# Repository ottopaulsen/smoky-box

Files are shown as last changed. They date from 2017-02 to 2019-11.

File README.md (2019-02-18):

# Smoky Box

Se beskrivelse i [smoky](https://github.com/ottopaulsen/smoky)

## NodeMCU

NodeMCU Pinout

## Vifte

Cooler Master A9225-...
12V, 0.6A

Pinout:
Sort: GND
Rød: 12V
Gul: Sense. Open collector. Kan kobles til 3,3V eller 5V. Frekvens forteller hastighet.
Blå: Control. PWM kontrollerer farta. 3,3V fungerer.

Use analogWrite() to write a value between 0 and 1023 on any of pin 0-8. You may not use the serial port if you use the serial pins.

## Components

DHT22 pinout:

DHT22 Pinout

The DHT22 is connected using a 3 pin 3,5mm jack as follows:

* GND is connected to the outer part
* VCC is connected to the middle part
* Data is connected to the inner part (center)

## Generell doc

[ESP8266 Reference Doc](http://arduino.esp8266.com/versions/1.6.5-1160-gef26c5f/doc/reference.html) Lots of useful information.

[How to connect and program the ESP8266](doc/ESP8266 Programming.md)

[Programming the NodeMCU](doc/NodeMCU.md)

[220V Detector](doc/220V detector.md)

[OTA Update](http://esp8266.github.io/Arduino/versions/2.0.0/doc/ota_updates/ota_updates.html) "Over the air" update av firmware i ESP8266. Jeg bruker [Web Browser varianten](http://esp8266.github.io/Arduino/versions/2.0.0/doc/ota_updates/ota_updates.html#web-browser)

[Integrating with Homekit](doc/Homekit.md)

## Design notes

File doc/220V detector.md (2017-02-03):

# 220C Detektor for varmeelement

Jeg ønsker å bruke røykskapet også for tørking av kjøtt. Hvis det skal skje om vinteren ønsker jeg å unngå at det fryser. Derfor har jeg installert et varmeelement på 100W, som styres av en termostat. For å finne ut hvor mye strøm som går med til denne oppvarmingen ønsker jeg å detektere når varmeelementet er på og når det er av, og så beregne strømforbruket ut fra dette.

Jeg må derfor koble 220V-signalet til varmeelementet inn på arduinoen. Dette gjør jeg via en [HLK-PM03](http://www.ebay.com/itm/272252759542?_trksid=p2057872.m2749.l2649&ssPageName=STRK%3AMEBIDX%3AIT) 220V AC til 5V DC omformer. Jeg skal vurdere å også bruke en optocoupler for å være sikker på at forstyrrelser på 220V-nettet ikke ødelegger arduinoen.

Min optocoupler er en EL817 ([datasheet](http://www.everlight.com/file/ProductFile/EL817.pdf)). Spenning inn skal være 1.2V, og den trekker 60 mA. Motstanden mellom anode og 5V skal da være:

R = U / I = (5V-1.2V) / 0.06A = 63 ohm.

Hvis jeg derimot bruker en 3.3V kilde skal motstanden være:

R = U / I = (3.3V-1.2V) / 0.06A = 35 ohm.

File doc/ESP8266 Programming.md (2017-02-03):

# ESP8266 Programming

The ESP8266 is a very affordable board with built in wifi, that can be programmed like an Arduino. It is small in size, but the simplest version only have two GPIO-ports. There are however other versions with more connections.

## Connecting the ESP8266 for flashing

In order to program it you need to connect it to your computer via an FTDI adapter. It may get power from your USB port via the FTDI adapter, provided you have an FTDI adapter with 3.3V output, but that is risky, since the wifi module uses a lot of power. I crashed my mac doing that, so I connected it to a separate power supply in stead.

Here is how you connect it all together for programming (flashing) the ESP8266 with your own software, for example using the Arduino IDE:

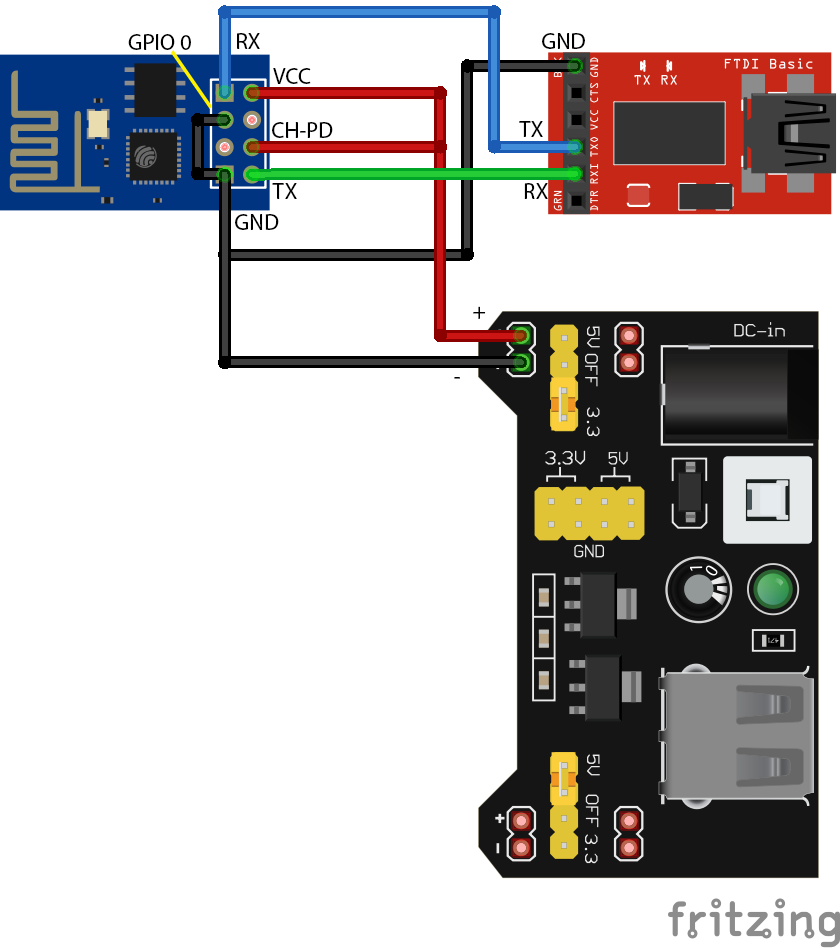
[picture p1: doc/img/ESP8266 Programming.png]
ESP8266 connection for programming


The power supply used here is a breadboard power supply that is connected to a 12V power supply and outputs 3.3V and 5V. You can use anything that gives you 3.3V with a few hundred milliamps.

Make sure you use the 3.3V power to the ESP8266!

There are many different ESP8266 boards, and many different FTDI adapters, so make sure you connect them right.

Also make sure you use 3.3V I/O level on the FTDI board. The FT232RL has a jumper where you can switch between 3.3V and 5V, and is convenient. If you only have 5V FTDI, buy a new, or create a voltage divider using two resistors on the TX port, so the RX port on the ESP8266 gets 3.3V.

### Wire connections

ESP8266          | FTDI             | Power            
---------------- | ---------------- | -----------------
GND              | GND              | GND (-)          
VCC              | <Do NOT connect> | + 3.3V           
RX               | TX               |                  
TX               | RX               |                  
CH-PD to VCC     |                  |                  
GPIO 0 to GND    |                  |                  
                 | USB to computer  | Power input for example from a std. 12V power supply

* Connect GND (-) on all boards together.
* The FTDI board gets VCC (+) from the USB port. VCC on the FTDI board should NOT be connected.
* Connect RX to TX and vice versa. 
* CH-PD is connected to VCC for some reason I don't remember.
* GPIO 0 is connected to GND to boot the ESP8266 in flash mode. Remember, this connection is for flashing.

-----

Here is pinout for this version of the ESP8266:

ESP8266 Pinout

Since you are probably going to connect the ESP8266 this way many times, it is a good idea to create a special cable for this purpose. Here is mine:

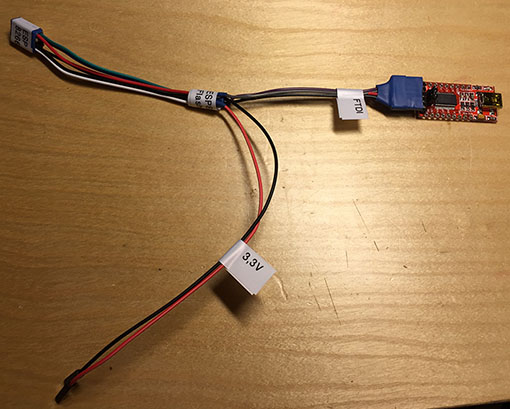
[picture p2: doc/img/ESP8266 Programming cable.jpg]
ESP8266 Programming cable


I used standard dupont wire cables for all the pins, and just cut away the wires on unused connectors. Then I used shrink plastic to hold them together, but tape would probably also do. The cables that should be connected to multiple ends, I soldered in the middle, and isolated with shrink plastic (tape would do).

## Flashing the ESP8266

You can use the Arduino IDE, and write code as for any other Arduino, to program the ESP8266. Just remember that it has very limited IO-ports.

Connect the board to the computer using an FTDI adapter, an external power supply and a cable as described above.

Please note that you need to install a driver for the FDTI adapter, if you haven't done that before.

In the Arduino IDE, select the right port for the FTDI adapter. On my mac it is /dev/cu.usbserial-A50285BI, but it may be different. It is easy to find, because it is visible in the Arduino IDE menu when the FTDI adapter is connected (and the driver is installed), and not visible when not connected.

Some times I have to restart my mac in order to find the USB port in the Arduino IDE. I haven't tried to find out why.

As board, select "Generic ESP8266 Module". If it is not there, it can be installed using the Board manager. Search for ESP8266.

### Example

As an example for using the ESP8266, I have connected it to a DHT22 which can read temperature and humidity, and I transfer the data to [ThingsPeak.com](https://thingspeak.com/) via wifi so I can read them on the internet.

Here is the wiring:

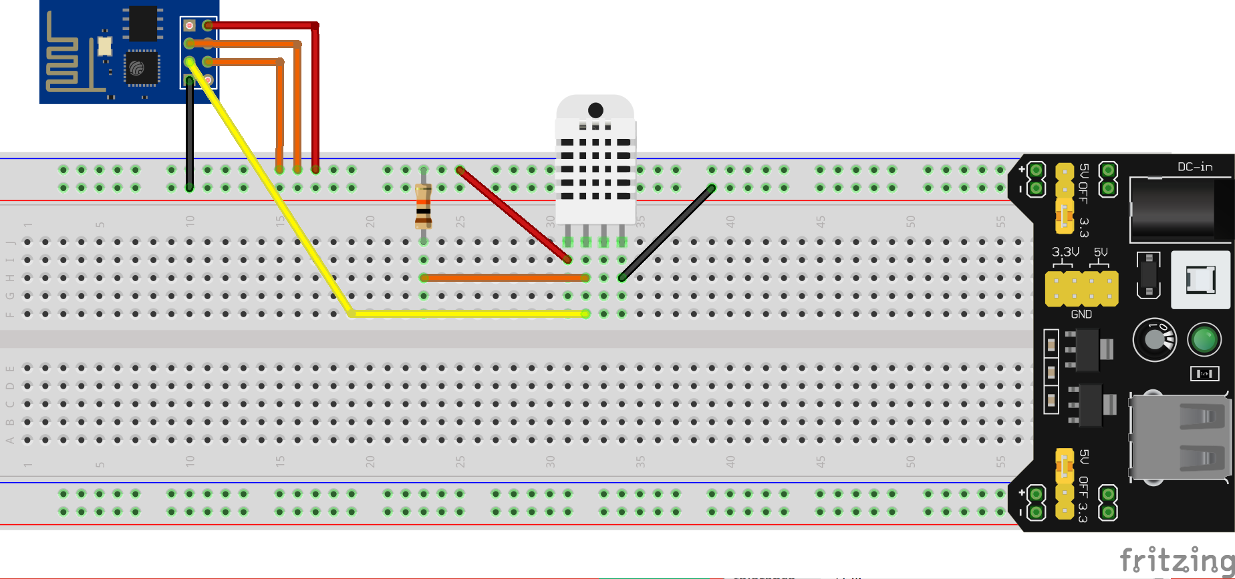
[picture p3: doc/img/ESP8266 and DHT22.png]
ESP8266 and DHT22 wiring


Double check that you are using 3.3V from the power supply!

In order to use ThingSpeak.com, just create an account and a channel. It is very easy. You need to find the channel id and the API key in there, but that should not be too hard.

Below is the example code. It reads humidity and temperature from the sensor, and transfer it to ThingSpeak.com every minute.

```cpp
#include "DHT.h"
#include "ThingSpeak.h"
#include "ESP8266WiFi.h"

#define DHTPIN 2
#define DHTTYPE DHT22

DHT dht(DHTPIN, DHTTYPE);
WiFiClient  client;

char ssid[] = "YourNetwork";
char pass[] = "yournetworkpassword";
unsigned long myChannelNumber = 12345;
const char * myWriteAPIKey = "SECRETTHINGSPEAKKEY";

long previousMillis = 0;
long interval = 60000;

void setup() {
  WiFi.begin(ssid, pass);
  ThingSpeak.begin(client);
  dht.begin();
}

void loop() {
  unsigned long currentMillis = millis();
  if(currentMillis - previousMillis > interval) {
    previousMillis = currentMillis;
    float temperature = dht.readTemperature();
    float humidity = dht.readHumidity();
    ThingSpeak.setField(1, temperature);
    ThingSpeak.setField(2, humidity);
    ThingSpeak.writeFields(myChannelNumber, myWriteAPIKey);
  }
}
```
Create a new Arduino project, paste the code, enter the right data for

* Wifi network SSID
* Wifi password
* ThingSpeak channel
* ThingSpeak API key

Compile and upload the code to the ESP8266 using the flash connection above. Remove the flash-connector and connect the parts as described above with the DHT22. Power up, wait a minute and take a look at ThingSpeak.com.

In order to just test ThingSpeak.com, here is a very simple Python script that transfers som fake data:

```python
import requests
import random
from time import sleep

url = 'https://api.thingspeak.com/update'
key = 'SECRETTHINGSPEAKKEY2'
channel = 12346

temp = random.uniform(10,25)
hum = random.uniform(10, 80)

for t in range(120):
    temp += random.random() - 0.5
    hum += (random.random() - 0.5) * 3
    data = {'channel_id': channel, 'api_key': key, 'field1': temp, 'field2': hum}
    res = requests.post(url, data=data)
    if res.status_code == 200:
        print('Successfully updated channel with:  Temp: {}   Hum: {}'.format(temp, hum))
    sleep(60)

```

Thingspeak logo white
Channels 
Apps
Blog
Support 
Account 
Sign Out
Smoky
Channel ID: 144820
Author: ottopaulsen
Access: Public Data from smoke house
Private View
Public View
Channel Settings
API Keys
Data Import / Export

 Add Visualizations  Data Export
MATLAB Analysis MATLAB Visualization
Channel Stats
Created 12 days ago
Updated less than a minute ago
Last Entry  less than a minute ago
5434 Entries
Field 1 Chart

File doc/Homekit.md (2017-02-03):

# Integrating with Homekit

## Introduction

I want to control the smoky box from my iPhone, and why not use [Homekit](https://developer.apple.com/library/content/documentation/NetworkingInternet/Conceptual/HomeKitDeveloperGuide/Introduction/Introduction.html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)? There is a tool called [Homebridge](https://github.com/nfarina/homebridge) that can be used to integrate with Homekit.

I have a Raspberry Pi 3 with [Ubuntu Mate](https://ubuntu-mate.org/) installed. It is doing almost nothing, so I want to install homebridge there, for this purpose.

## Installation log

Ubuntu Mate is already running on my Pi, so I start following the [installation instructions](https://github.com/nfarina/homebridge#installation) for Homebridge, including some of the things mentioned in the Raspberry Pi [Wiki](https://github.com/nfarina/homebridge/wiki/Running-HomeBridge-on-a-Raspberry-Pi).

One note about [Installing Homebridge and dependencies](https://github.com/nfarina/homebridge/wiki/Running-HomeBridge-on-a-Raspberry-Pi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): On Ubuntu Mate, the node_modules are installed under `/usr/lib`, not `/usr/local/lib`.

Installed the [homebridge-mqtt-temperature plugin](https://www.npmjs.com/package/homebridge-mqtt-temperature), the [homebridge-mqtt-humidity plugin](https://www.npmjs.com/package/homebridge-mqtt-humidity) and the [mqtt library](https://www.npmjs.com/package/mqtt).

According to the installation instructions for homebridge, it should not work until I created the config.json file. However, it did start without this file. Probably because there were some files under the accessories and the persist directories in the ~/.homebridge folder. I deleted those directories and created a new config.json file like this:
```
{
  "bridge": {
    "name": "HomeBridge-Otto",
    "username": "AC:33:3B:D3:CE:32",
    "port": 55149,
    "pin": "031-45-154"
  },

  "description": "Otto sin homebridge hjemme",

  "accessories": [
    {
      "accessory": "mqtt-temperature",
      "name": "Smoky temperatur",
      "url": "mqtt://m20.cloudmqtt.com:15555",
      "topic": "smoky/1/inside/temperature",
      "username": "henqvddw",
      "password": "hemmelig"
    },
    {
      "accessory": "mqtt-humidity",
      "name": "Smoky luftfuktighet",
      "url": "mqtt://m20.cloudmqtt.com:15555",
      "topic": "smoky/1/inside/humidity",
      "username": "henqvddw",
      "password": "hemmelig"
    }
  ],

  "platforms": []
}
```

The name can be anything.
I have tried to figure out what the username is, without luck, but you can change it to something with legal hex numbers, I think. I believe you can select the port you like (as long as it is not used by something else), and also the pin, but the format must be the same.

The accessory is the name of the plugins, and if you have an MQTT running, you will recognize the other values under accessories.

I found the homebridge in the Home app on my iPhone, but every time I restarted homebridge, I had to set ig up again. I dont know why. Should not be necessary.

## References

[Introduction to Homekit (apple)](https://developer.apple.com/library/content/documentation/NetworkingInternet/Conceptual/HomeKitDeveloperGuide/Introduction/Introduction.html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)

[Homebridge (Node)](https://github.com/nfarina/homebridge)

[Homebridge on RaspberryPi](https://github.com/nfarina/homebridge/wiki/Running-HomeBridge-on-a-Raspberry-Pi)

[Homecontrol (go)](http://selfcoded.com/homecontrol/)

[Plugin simple example](https://github.com/nfarina/homebridge/tree/6500912f54a70ff479e63e2b72760ab589fa558a/example-plugins/homebridge-lockitron)

[Homebridge MQTT switch](https://www.npmjs.com/package/homebridge-mqttswitch)

[Homebridge MQTT temperature](https://www.npmjs.com/package/homebridge-mqtt-temperature)

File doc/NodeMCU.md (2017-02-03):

# Programming the NodeMCU

In order to program the NodeMCU you need the [CH340 driver](http://www.wemos.cc/downloads/). That will (on mac) give you the /dev/cu.wchusbserial1420 port available in the Arduino IDE.

Then follow [these instructions](http://www.instructables.com/id/Quick-Start-to-Nodemcu-ESP8266-on-Arduino-IDE/) to try it using a blinking led.

Here is [pinout](https://github.com/nodemcu/nodemcu-devkit) and other info about the NodeMCU.

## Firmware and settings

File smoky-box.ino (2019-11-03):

#include <PubSubClient.h>
#include <DHTesp.h>
#include <ESP8266WiFi.h>
#include <ESP8266WebServer.h>
#include <ESP8266mDNS.h>
#include <ESP8266HTTPUpdateServer.h>
#include <PID_v1.h>
#include <EEPROM.h>

#include "secrets.h"
/*
 * Secrets are: 
 *   #define WIFIPASSWORD "secret"
 *   #define MQTTPASSWORD "secret"
 *   #define UPDATEOTAPASSWORD "secret"
 */

/* GPIO Allocation
 * 
 * D0 GPIO16
 * D1 GPIO5
 * D2 GPIO4 DHT Inside
 * D3 GPIO0
 * D4 GPIO2 DHT Outside
 * D5 GPIO14 DHT Box
 * D6 GPIO12 Heater
 * D7 GPIO13 Green LED
 * D8 GPIO15 
 * RX GPIO3 Fan vent PWM
 * TX GPIO1 Fan vent sensor
 */

#define SMOKY_ID "1"
#define PRODUCTION 1 // 1 to go Live, 0 to test

// WiFi
const char* wifiSsid = "Xtreme";
const char* wifiPassword = WIFIPASSWORD;
WiFiClient  wifiClient;

// MQTT
const char* mqttServer = "10.0.0.15";
const char* mqttUser = "ottomq";
const char* mqttPassword = MQTTPASSWORD;
const long mqttPort = 1883;
const long mqttInterval = 10000;
unsigned long mqttPreviousSentMillis = 0;
PubSubClient mqttClient(wifiClient);

// MQTT Topics
#define MQTT_TOPIC_OUT "smoky/" SMOKY_ID
#define MQTT_TOPIC_IN "smoky/" SMOKY_ID "/in"
const char* mqttTopicInsideTemperature = MQTT_TOPIC_OUT "/inside/temperature";
const char* mqttTopicInsideHumidity = MQTT_TOPIC_OUT "/inside/humidity";
const char* mqttTopicOutsideTemperature = MQTT_TOPIC_OUT "/outside/temperature";
const char* mqttTopicOutsideHumidity = MQTT_TOPIC_OUT "/outside/humidity";
const char* mqttTopicBoxTemperature = MQTT_TOPIC_OUT "/box/temperature";
const char* mqttTopicBoxHumidity = MQTT_TOPIC_OUT "/box/humidity";
const char* mqttTopicSmoke = MQTT_TOPIC_OUT "/inside/smoke";
const char* mqttTopicHeaterPercent = MQTT_TOPIC_OUT "/inside/heaterpercent";
const char* mqttTopicHeaterOutput = MQTT_TOPIC_OUT "/inside/heateroutput";
const char* mqttTopicOutSettingsTemp = MQTT_TOPIC_OUT "/settings/temp";
const char* mqttTopicOutSettingsKp = MQTT_TOPIC_OUT "/settings/kp";
const char* mqttTopicOutSettingsKi = MQTT_TOPIC_OUT "/settings/ki";
const char* mqttTopicOutSettingsKd = MQTT_TOPIC_OUT "/settings/kd";
const char* mqttTopicOutSettingsFanVent = MQTT_TOPIC_OUT "/settings/fan_vent";
const char* mqttTopicOutSettingsHeaterOutput = MQTT_TOPIC_OUT "/settings/heateroutput";
const char* mqttTopicOutConnecting = MQTT_TOPIC_OUT "/connecting";
const char* mqttTopicDhtReadFailures = MQTT_TOPIC_OUT "/dhtreadfailures";
const char* mqttTopicOutMsg = MQTT_TOPIC_OUT "/msg";
const char* mqttTopicFanVentSetting = MQTT_TOPIC_OUT "/fan_vent/setting";
const char* mqttTopicFanVentSpeed = MQTT_TOPIC_OUT "/fan_vent/speedRPM";
const char* mqttTopicLooptimeMax = MQTT_TOPIC_OUT "/looptime/max";
const char* mqttTopicLooptimeMin = MQTT_TOPIC_OUT "/looptime/min";
const char* mqttTopicLooptimeAverage = MQTT_TOPIC_OUT "/looptime/average";
const char* mqttTopicLooptimeLatest = MQTT_TOPIC_OUT "/looptime/latest";
const char* mqttTopicLooptimeCount = MQTT_TOPIC_OUT "/looptime/count";

const char* mqttTopicInAck = MQTT_TOPIC_IN "/ack";
const char* mqttTopicInSetTemp = MQTT_TOPIC_IN "/temp";
const char* mqttTopicInSetKp = MQTT_TOPIC_IN "/kp";
const char* mqttTopicInSetKi = MQTT_TOPIC_IN "/ki";
const char* mqttTopicInSetKd = MQTT_TOPIC_IN "/kd";
const char* mqttTopicInSetFanVent = MQTT_TOPIC_IN "/fan_vent";
const char* mqttTopicInReadSettings = MQTT_TOPIC_IN "/read";

// MQTT Status
#define MQTT_STATUS_UNKNOWN 0
#define MQTT_STATUS_SENDING 1
#define MQTT_STATUS_ACKNOWLEDGED 2
#define MQTT_STATUS_FAILED 3
#define GREENLED 13
const long ledInterval = 250;
unsigned int mqttStatus = MQTT_STATUS_UNKNOWN;
bool greenLed = false;
unsigned long ledPreviousMillis = 0;

// Smoke
#define SMOKEPIN A0

// Temperature and humidity
#define DHTINSIDE 4 // D2
#define DHTOUTSIDE 2 // D4
#define DHTBOX 14 // D5

#define DHTTYPE DHTesp::AM2302
DHTesp dhtInside;
DHTesp dhtOutside;
DHTesp dhtBox;
double temperatureInside =  5.0;
float humidityInside = 0.0;
float temperatureOutside = 0.0;
float humidityOutside = 0.0;
float temperatureBox = 0.0;
float humidityBox = 0.0;
unsigned long dhtReadFailures = 0;
unsigned long dhtReadInterval = 2500; 
unsigned long dhtPreviousReadMillis = 0;

// EEPROM Settings
#define SETTINGS_VERSION 101
#define DEFAULT_KP 5.0
#define DEFAULT_KI 0.05
#define DEFAULT_KD 0.5
#define DEFAULT_TEMP 5.0
#define DEFAULT_FAN 10
struct SmokySettings {
  int version; // Figure ot if data has been saved before
  float Kp;
  float Ki;
  float Kd;
  double temp;
  int fanVent;
};
SmokySettings settings;


// Heater control
#define HEATERPIN 12 // D6
#define HEATER_PID_SAMPLE_TIME 1000
unsigned long pidWindowSize = 5000;
unsigned long maxHeaterOutput = 100;
bool heaterOn = false;
unsigned long heaterPreviousCalcMillis = 0;
unsigned long heaterPreviousPidWindow = 0;
double heaterOutput = 0.0;
PID heaterPID(&temperatureInside, &heaterOutput, &(settings.temp), settings.Kp, settings.Ki, settings.Kd, DIRECT);


// Smoke
float smoke = 0.0;

// OTA Update
// http://esp8266.github.io/Arduino/versions/2.0.0/doc/ota_updates/ota_updates.html
const char* host = "smoky-update";
const char* update_path = "/firmware";
const char* update_username = "admin";
const char* update_password = UPDATEOTAPASSWORD;
ESP8266WebServer httpServer(80);
ESP8266HTTPUpdateServer httpUpdater;

// Fan ventilation
#define FAN_VENT_SENSOR_PIN 1 // D10 or TX
#define FAN_VENT_PWM_PIN 3 // D9 or RX
unsigned long fanVentSpeedRPM = 0; // Actual speed
volatile unsigned long fanVentCount = 0;

// Fan common
unsigned long previousFanMillis = 0;
unsigned long fanInterval = 500;

// Loop time
unsigned long looptime = 0;
unsigned long previousLooptime = 0;
unsigned long maxLooptime = 0;
unsigned long minLooptime = 9999;
unsigned long latestLooptime = 0;
unsigned long loopCount = 0;
double averageLooptime = 0.0;


void setup() {

  // delay(1000);

  // Serial.begin(115200);
  // Serial.println();
  // Serial.println("Starting");

  EEPROM.begin(256);
  readSettingsFromEEPROM();

  // WiFi
  delay(100);
  // Serial.print("Starting wifi");
  WiFi.begin(wifiSsid, wifiPassword);
  while (WiFi.status() != WL_CONNECTED) {
    // Serial.print(".");
    delay(500);
  }
  // Serial.println("Connected");

  // Temperature and humidity
  dhtInside.setup(DHTINSIDE, DHTTYPE);
  dhtOutside.setup(DHTOUTSIDE, DHTTYPE);
  dhtBox.setup(DHTBOX, DHTTYPE);
  dhtPreviousReadMillis = 0;
  loopReadTempHumid(); // Initial reading to get the temp controller a better start.

  // MQTT
  mqttClient.setServer(mqttServer, mqttPort);
  mqttClient.setCallback(mqttCallback);
  randomSeed(micros());
  pinMode(GREENLED, OUTPUT);

  delay(100);

  // Heater
  pinMode(HEATERPIN, OUTPUT);
  heaterPID.SetOutputLimits(0, maxHeaterOutput);
  heaterPID.SetMode(AUTOMATIC);
  heaterPID.SetSampleTime(HEATER_PID_SAMPLE_TIME);
  heaterPreviousPidWindow = millis();
  heaterPID.SetTunings(settings.Kp, settings.Ki, settings.Kd);

  // OTA Update
  // Can only be done if the file is less than half the memory size
  // NodeMCU v2 and v3 memory is 4MB
  MDNS.begin("smoky");
  httpUpdater.setup(&httpServer, update_path, update_username, update_password);
  httpServer.begin();
  MDNS.addService("http", "tcp", 80);

  // LED
  ledPreviousMillis = 0;

  // Fan ventilation
  pinMode(FAN_VENT_PWM_PIN, OUTPUT);
  attachInterrupt(digitalPinToInterrupt(FAN_VENT_SENSOR_PIN), countFanVent, RISING);
  pinMode(FAN_VENT_SENSOR_PIN, INPUT_PULLUP);

  writeMqttSettings();
  // Serial.println("Setup done");

}

void readSettingsFromEEPROM(){
  int eeAddress = 0;
  // mqttSend(mqttTopicOutMsg, String("Reading EEPROM").c_str());
  EEPROM.get(eeAddress, settings);
  
  if(settings.version != SETTINGS_VERSION){
    // mqttSend(mqttTopicOutMsg, String("EEPROM - Not found version").c_str());
    settings.version = SETTINGS_VERSION;
    settings.Kp = DEFAULT_KP;
    settings.Ki = DEFAULT_KI;
    settings.Kd = DEFAULT_KD;
    settings.temp = DEFAULT_TEMP;
    settings.fanVent = DEFAULT_FAN;
    EEPROM.put(0, settings);
  }
}

void writeSettingsToEEPROM(){
  int eeAddress = 0;
  mqttSend(mqttTopicOutMsg, String("Writing EEPROM").c_str());
  EEPROM.put(eeAddress, settings);
  EEPROM.commit();
}

void loop() {
  calcLoopTime();
  loopBlinkLed();
  loopReadTempHumid();
  loopBlinkLed();
  loopControlHeater();
  loopBlinkLed();
  smoke = analogRead(SMOKEPIN);
  loopBlinkLed();
  loopWriteMqtt();
  loopBlinkLed();
  mqttClient.loop();
  loopBlinkLed();
  loopFan();

  // OTA Update
  httpServer.handleClient();
}

void calcLoopTime(){
  looptime = millis();
  if(looptime < previousLooptime){
    // Wrapped around. Reset time variables.
    resetTimeVariables();
  }
  latestLooptime = looptime - previousLooptime;
  if (loopCount){
    averageLooptime += (double) latestLooptime / loopCount;
    if (latestLooptime < minLooptime){
      minLooptime = latestLooptime;
    }
    if (latestLooptime > maxLooptime){
      maxLooptime = latestLooptime;
    }
  }
  previousLooptime = looptime;
  loopCount++;
}

void resetTimeVariables(){
  previousLooptime = 0;
  loopCount = 0;
  averageLooptime = 0;
  minLooptime = 9999;
  maxLooptime = 0;
  dhtPreviousReadMillis = 0;
  heaterPreviousPidWindow = 0;
  mqttPreviousSentMillis = 0;
  previousFanMillis = 0;
  ledPreviousMillis = 0;
}

void loopReadTempHumid(){
  unsigned long currentMillis = millis();
  if (currentMillis - dhtPreviousReadMillis > dhtReadInterval) {
    temperatureInside =  dhtInside.getTemperature();
    humidityInside = dhtInside.getHumidity();
    temperatureOutside = dhtOutside.getTemperature();
    humidityOutside = dhtOutside.getHumidity();
    temperatureBox = dhtBox.getTemperature();
    humidityBox = dhtBox.getHumidity();
    if (isnan(temperatureInside)) {
      dhtReadFailures++;
      if(PRODUCTION) mqttSend(mqttTopicOutMsg, String("DHT22 Inside read error").c_str());
    }
    if (isnan(temperatureOutside)) {
      dhtReadFailures++;
      if(PRODUCTION) mqttSend(mqttTopicOutMsg, String("DHT22 Outside read error").c_str());
    }
    if (isnan(temperatureBox)) {
      dhtReadFailures++;
      if(PRODUCTION) mqttSend(mqttTopicOutMsg, String("DHT22 Box read error").c_str());
    }
    dhtPreviousReadMillis = currentMillis;
  }
}

void loopControlHeater(){

  heaterPID.Compute();
  if (isnan(temperatureInside) || isnan(heaterOutput)) {
    heaterOutput = 0.0;
  }
  
  if (looptime - heaterPreviousPidWindow > pidWindowSize) { //time to shift the Relay Window
    heaterPreviousPidWindow += pidWindowSize;
  }
  if (heaterOutput > maxHeaterOutput * (looptime - heaterPreviousPidWindow) / pidWindowSize) {
    digitalWrite(HEATERPIN, HIGH); // On
    heaterOn = true;
  } else {
    digitalWrite(HEATERPIN, LOW); // Off
    heaterOn = false;
  }
}

void loopWriteMqtt(){
  if(looptime - mqttPreviousSentMillis >= mqttInterval) {
    writeMqtt();
    mqttPreviousSentMillis = looptime;
  }  
}

void loopFan(){
  unsigned long currentMillis = millis();
  if(currentMillis - previousFanMillis >= fanInterval) {
    unsigned long countTime = currentMillis - previousFanMillis;
    noInterrupts();
    fanVentSpeedRPM = (fanVentCount * (30000 / countTime)); // 1000 ms * 60 sek / 2 counts per round
    fanVentCount = 0;
    interrupts();
    previousFanMillis = currentMillis;
    analogWrite(FAN_VENT_PWM_PIN, map(settings.fanVent, 0, 100, 0, 1023));
  }
}

void countFanVent(){ 
  fanVentCount++;
}

void mqttSend(const char* topic, const char* msg){
  reconnectMqtt();
  mqttClient.publish(topic, msg); 
}

void loopBlinkLed(){
  /* 
   * Control the green LED.
   * Start blinking when data is sent to MQTT
   * Constant on when ACK is received from MQTT
   * TO DO: Constant off if no ACK is received within the timeout.
   *
   * I am calling this multiple times in the loop, to get a more stable blinking frequency.
   */
  unsigned long currentMillis = millis();
  if(currentMillis - ledPreviousMillis >= ledInterval) {
    if(mqttStatus == MQTT_STATUS_ACKNOWLEDGED){
      greenLed = true;
    } else if(mqttStatus == MQTT_STATUS_SENDING){
      greenLed = not greenLed;
    } else {
      greenLed = false;
    }
    ledPreviousMillis = currentMillis;
    if(greenLed) {
      digitalWrite(GREENLED, HIGH);
    } else {
      digitalWrite(GREENLED, LOW);
    }
  }
  
}


void writeMqtt(){
  mqttStatus = MQTT_STATUS_SENDING;
  reconnectMqtt();

  if (!isnan(temperatureInside)) {
    mqttClient.publish(mqttTopicInsideTemperature, String(temperatureInside).c_str());
    mqttClient.publish(mqttTopicInsideHumidity, String(humidityInside).c_str());
  }
  if (!isnan(temperatureOutside)) {
    mqttClient.publish(mqttTopicOutsideTemperature, String(temperatureOutside).c_str());
    mqttClient.publish(mqttTopicOutsideHumidity, String(humidityOutside).c_str());
  }
  if (!isnan(temperatureBox)) {
    mqttClient.publish(mqttTopicBoxTemperature, String(temperatureBox).c_str());
    mqttClient.publish(mqttTopicBoxHumidity, String(humidityBox).c_str());
  }

  mqttClient.publish(mqttTopicSmoke, String(smoke).c_str());
  mqttClient.publish(mqttTopicHeaterOutput, (String(heaterOutput)).c_str());
  mqttClient.publish(mqttTopicDhtReadFailures, (String(dhtReadFailures)).c_str());
//  mqttClient.publish(mqttTopicFanVentSpeed, (String(fanVentSpeedRPM)).c_str());

//  mqttClient.publish(mqttTopicLooptimeMax, (String(maxLooptime)).c_str());
//  mqttClient.publish(mqttTopicLooptimeMin, (String(minLooptime)).c_str());
//  mqttClient.publish(mqttTopicLooptimeLatest, (String(latestLooptime)).c_str());
//  mqttClient.publish(mqttTopicLooptimeAverage, (String(averageLooptime)).c_str());
//  mqttClient.publish(mqttTopicLooptimeCount, (String(loopCount)).c_str());

}

void writeMqttSettings(){
  mqttStatus = MQTT_STATUS_SENDING;
  reconnectMqtt();

  mqttClient.publish(mqttTopicOutSettingsTemp, String(settings.temp).c_str());
  mqttClient.publish(mqttTopicOutSettingsHeaterOutput, String(heaterOutput).c_str());
  mqttClient.publish(mqttTopicOutSettingsKp, String(settings.Kp).c_str());
  mqttClient.publish(mqttTopicOutSettingsKi, String(settings.Ki).c_str());
  mqttClient.publish(mqttTopicOutSettingsKd, String(settings.Kd).c_str());
  mqttClient.publish(mqttTopicOutSettingsFanVent, String(settings.fanVent).c_str());
}

void reconnectMqtt() {
  if (!mqttClient.connected()) {
    // Create a random client ID
    String clientId = "smoky-" SMOKY_ID;
    // Attempt to connect
    if (mqttClient.connect(clientId.c_str(), mqttUser, mqttPassword)) {
      // Once connected, publish an announcement...
      if(mqttStatus == MQTT_STATUS_UNKNOWN) {
        mqttClient.publish(mqttTopicOutConnecting, "Smoky starting");
      } else {
        mqttClient.publish(mqttTopicOutConnecting, "Smoky reconnecting");
      }

      mqttClient.subscribe(MQTT_TOPIC_IN "/#", 1);
    }
  }
}

void mqttCallback(char* topic, byte* payload, unsigned int length) {
  if(strcmp(topic, mqttTopicInAck) == 0) {
    // Set status to turn on green led if ack is received
    mqttStatus = MQTT_STATUS_ACKNOWLEDGED;
  } else if(strcmp(topic, mqttTopicInSetTemp) == 0) {
    // Set temp
    settings.temp = payloadToFloat(payload, length, settings.temp);
    writeSettingsToEEPROM();
    mqttSend(mqttTopicOutSettingsTemp, String(settings.temp).c_str());
  } else if(strcmp(topic, mqttTopicInSetKp) == 0) {
    // Set Kp
    settings.Kp = payloadToFloat(payload, length, settings.Kp);
    heaterPID.SetTunings(settings.Kp, settings.Ki, settings.Kd);
    writeSettingsToEEPROM();
    mqttSend(mqttTopicOutSettingsKp, String(settings.Kp).c_str());
  } else if(strcmp(topic, mqttTopicInSetKi) == 0) {
    // Set Ki
    settings.Ki = payloadToFloat(payload, length, settings.Ki);
    heaterPID.SetTunings(settings.Kp, settings.Ki, settings.Kd);
    writeSettingsToEEPROM();
    mqttSend(mqttTopicOutSettingsKi, String(settings.Ki).c_str());
  } else if(strcmp(topic, mqttTopicInSetKd) == 0) {
    // Set Kd
    settings.Kd = payloadToFloat(payload, length, settings.Kd);
    heaterPID.SetTunings(settings.Kp, settings.Ki, settings.Kd);
    writeSettingsToEEPROM();
    mqttSend(mqttTopicOutSettingsKd, String(settings.Kd).c_str());
  } else if(strcmp(topic, mqttTopicInSetFanVent) == 0) {
    // Set ventilation fan speed
    int setting = payloadToInt(payload, length, settings.fanVent);
    if (setting < 0) setting = 0;
    if (setting > 100) setting = 100;
    settings.fanVent = setting;
    writeSettingsToEEPROM();
    mqttSend(mqttTopicOutSettingsFanVent, String(settings.fanVent).c_str());
  } else if(strcmp(topic, mqttTopicInReadSettings) == 0) {
    // Read settings
    writeMqttSettings();
  }
}

double payloadToFloat(byte* payload, unsigned int length, double defaultValue){
  payload[length] = '\0';
  String s = String((char*)payload);
  double f = (double) s.toFloat();
  if (f == 0.0 && payload[0] != '0') return defaultValue;
  else return f;
}

int payloadToInt(byte* payload, unsigned int length, int defaultValue){
  payload[length] = '\0';
  String s = String((char*)payload);
  int f = s.toInt();
  if (f == 0 && payload[0] != '0') return defaultValue;
  else return f;
}

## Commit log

2017-02-02 Add fan control and remove serial output
2017-03-07 Clean up and adjust PID loop
2017-03-08 Fix PID at boot time. Also make some loop surveyllance
    [smoky-box.ino]
2019-11-03 Remove circulation fan
